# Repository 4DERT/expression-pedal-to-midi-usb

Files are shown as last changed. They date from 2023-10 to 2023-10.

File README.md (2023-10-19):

# Expression pedal to MIDI USB

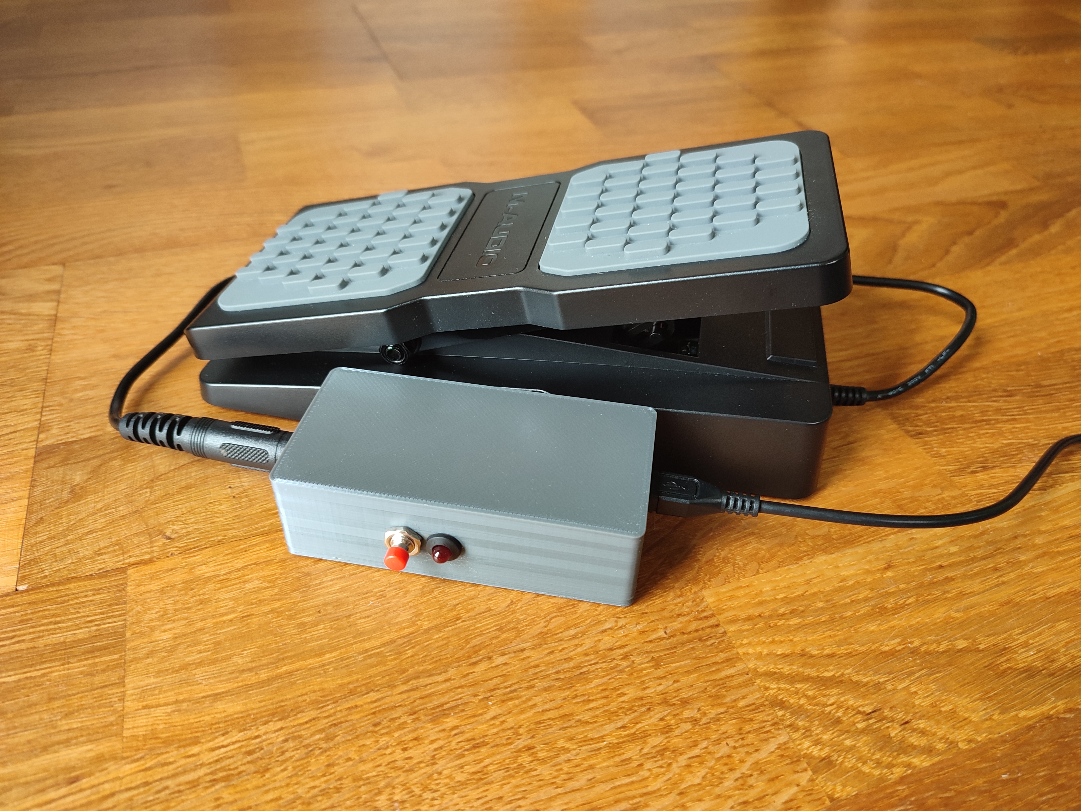
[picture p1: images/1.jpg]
<br>
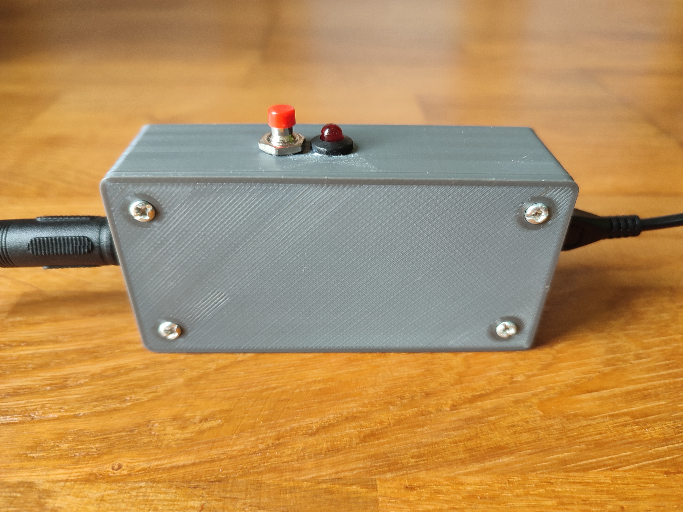
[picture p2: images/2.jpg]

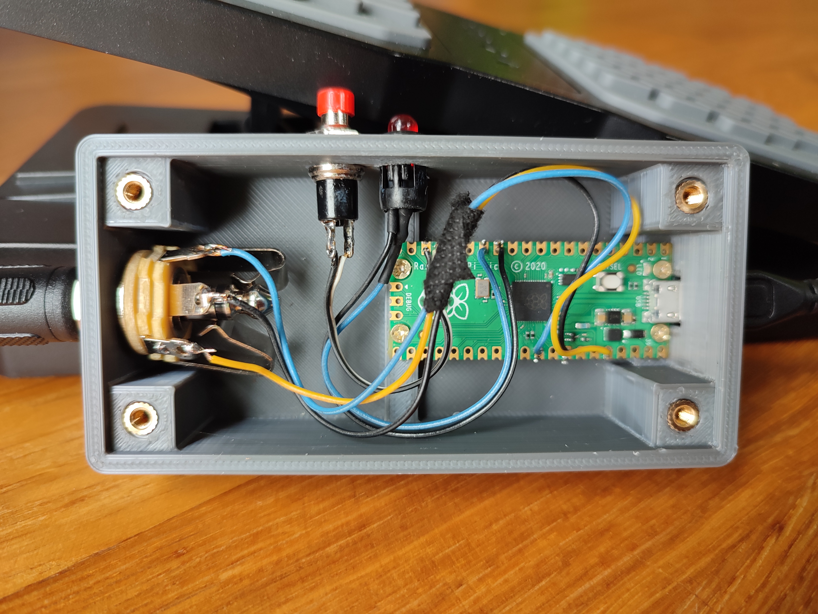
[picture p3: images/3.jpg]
<br>

A Raspberry Pi Pico-based device that takes an expression pedal output via a TRS 1/4" jack and converts it to a USB output.

## Instalation
Put your Raspberry Pi Pico into Bootsel mode by pressing the Bootsel button and then plug it into your computer. When the device appears as a mass storage device, simply drag and drop the UF2 file.

## Usage 
1. Connect the MIDI expression pedal to the 1/4" TRS stereo jack socket on the device.
2. Connect the device to your computer using a USB cable.
3. [Calibrate your device](#calibration)
4. Open your MIDI software on your computer (e.g., DAW) and configure it to receive data from the device.
5. Begin using the MIDI expression pedal, and the device will transmit the data to your computer.

## Calibration
1. Hold the button on the side of the device until the LED light starts flashing slowly.
2. Next, move your pedal from the minimum to the maximum position and set it approximately in the middle position.
3. Once you've completed step 2, press the button again. The LED will start flashing rapidly, indicating that the device is learning electrical noise values to prevent unintentional data transmission to the computer when you're not moving the pedal.
4. To finish the calibration process, press the button once more. The settings will be saved in the flash memory and will load automatically during the next device startup.

## Parts List:
- Raspberry Pi Pico
- 1/4" TRS stereo jack socket
- 5mm LED 
- [5mm LED Holder](https://www.amazon.com/50Pcs-Holder-Socket-Light-emitting-Plastic/dp/B07NRX2YNL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)
- 330 Ohm resistor
- [7mm Momentary Push button Switch](https://www.aliexpress.com/item/32790920961.html)
- Some cables
- 4x M2 6mm screws
- 4x M3 Thread Knurled Brass Threaded Heat Set
- 4x M3 Head Bolt

You can print the case on a 3D printer, the files are in the folder 'stl'

## Schematic
<br>

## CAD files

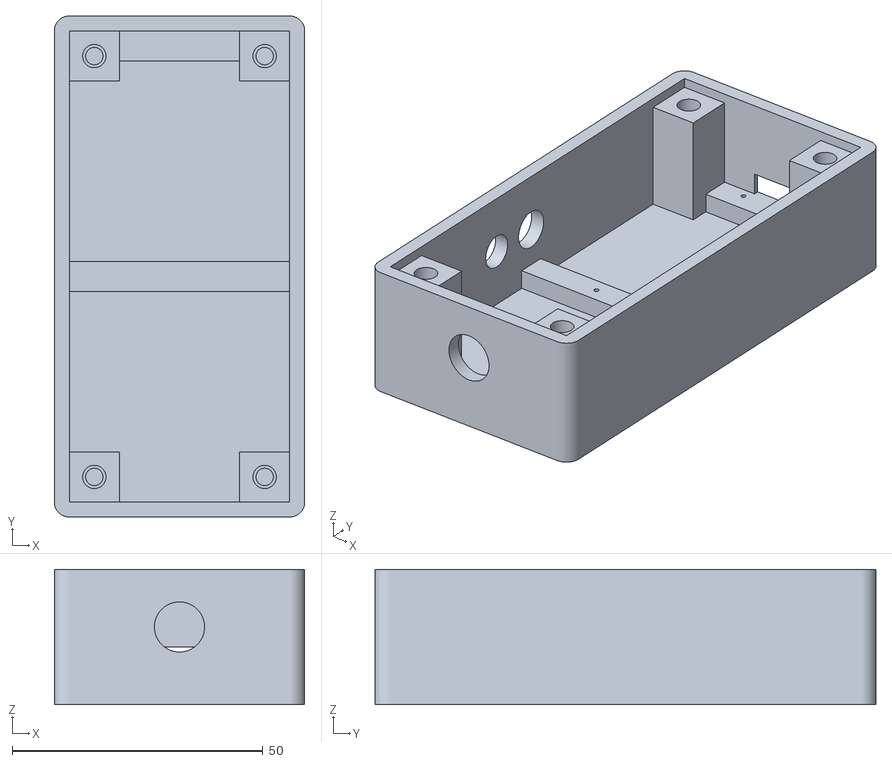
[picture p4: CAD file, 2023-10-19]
stl/midi_usb_main.stl
50.0 x 100.0 x 27.0

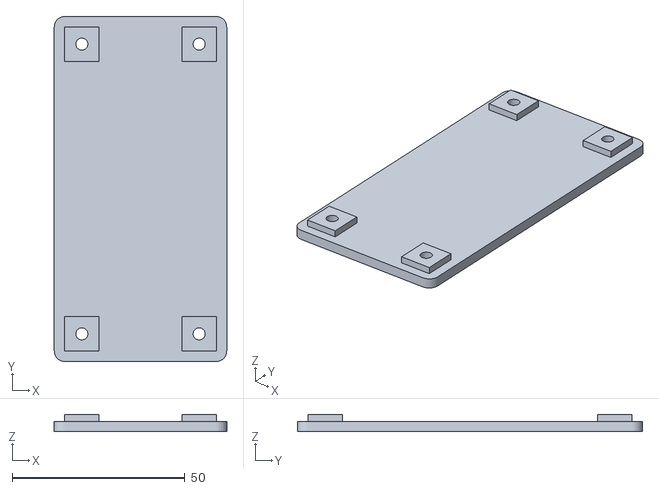
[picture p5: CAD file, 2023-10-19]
stl/midi_usb_top.stl
50.0 x 100.0 x 5.00

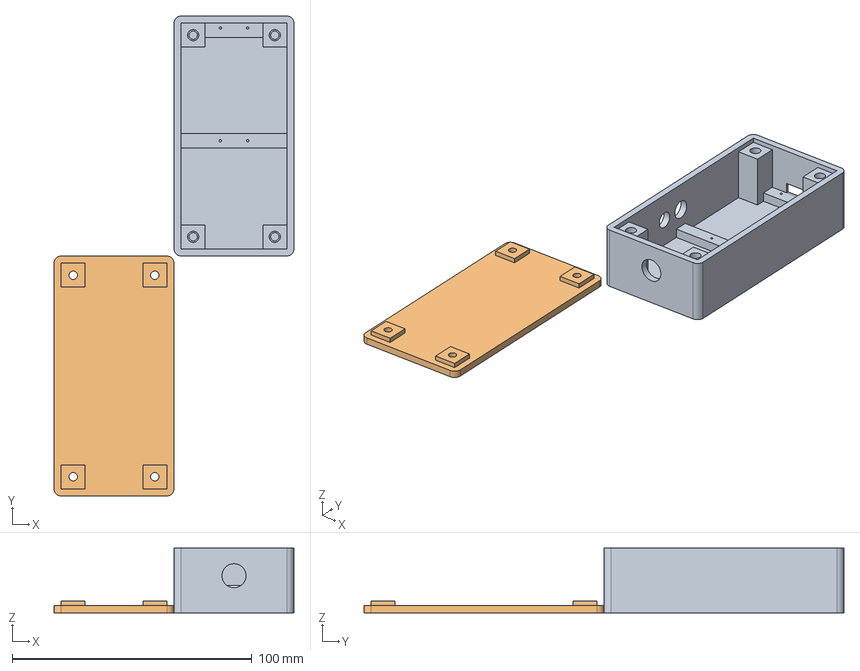
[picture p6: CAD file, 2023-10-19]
stl/midi_usb.FCStd
100.0 x 200.0 x 27.0 mm
base
top

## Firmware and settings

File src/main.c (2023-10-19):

#include <hardware/flash.h>
#include <hardware/gpio.h>
#include <pico/bootrom.h>
#include <stdint.h>
#include <stdio.h>
#include <stdlib.h>
#include <string.h>

#include "button.h"
#include "exp_pedal.h"
#include "flash.hpp"
#include "led.h"
#include "midi.h"
#include "pwm_modulation.h"
#include "tusb.h"

#define LED_GPIO 10
#define BUTTON_GPIO 13
#define PEDAL_GPIO 26
#define PEDAL_ADC_INPUT 0

#define BLINK_TIME_MS_CALIBRATION_1 500
#define BLINK_TIME_MS_CALIBRATION_2 100
#define BLINK_TIME_MS_USB_NOT_CONNECTED 2000

button_t button;
led_t led;

void read_midi_task(void);
void on_button_action(button_interaction_type interaction);

/*------------- MAIN -------------*/
int main(void) {
  // rescue option to enter bootsel
  const uint32_t btn = BUTTON_GPIO;
  gpio_init(btn);
  gpio_set_dir(btn, GPIO_IN);
  gpio_pull_up(btn);
  sleep_ms(250);
  if (!gpio_get(btn))
    reset_usb_boot(0, 0);

  // led init
  led.gpio = LED_GPIO;
  led_init(&led);
  led_blink(&led, BLINK_TIME_MS_USB_NOT_CONNECTED);
  led_pwm_pedal_modulation_init(&led);

  // button init
  button.gpio = BUTTON_GPIO;
  button_init(&button, on_button_action);

  // adc pedal init
  setup_exp_pedal(PEDAL_GPIO, PEDAL_ADC_INPUT);

  // read pedal calibration from flash
  flash_read(&expression_pedal_calibration, sizeof(expression_pedal_calibration));

  // init device stack on configured roothub port
  tud_init(BOARD_TUD_RHPORT);

  turn_on_pedal();

  while (1) {
    tud_task();
    read_midi_task();
    expression_pedal_task();
    button_task(&button);
    led_task(&led);
    led_pwm_pedal_modulation_task(get_current_pos_midi());
  }

  return 0;
}

//--------------------------------------------------------------------+
// Device callbacks
//--------------------------------------------------------------------+

// // Invoked when device is mounted
void tud_mount_cb(void) {
  led_off(&led);
  led_pwm_pedal_modulation_enable(&led);
}

// // Invoked when device is unmounted
void tud_umount_cb(void) { led_blink(&led, BLINK_TIME_MS_USB_NOT_CONNECTED); }

// // Invoked when usb bus is suspended
// // remote_wakeup_en : if host allow us  to perform remote wakeup
// // Within 7ms, device must draw an average of current less than 2.5 mA from bus
void tud_suspend_cb(bool remote_wakeup_en) {
  (void)remote_wakeup_en;
  led_off(&led);
  led_pwm_pedal_modulation_disable(&led);
}

// // Invoked when usb bus is resumed
void tud_resume_cb(void) {
  led_off(&led);
  led_pwm_pedal_modulation_enable(&led);
}

//--------------------------------------------------------------------+
// MIDI Task
//--------------------------------------------------------------------+

void read_midi_task(void) {
  // The MIDI interface always creates input and output port/jack descriptors
  // regardless of these being used or not. Therefore incoming traffic should be
  // read (possibly just discarded) to avoid the sender blocking in IO
  uint8_t packet[4];
  while (tud_midi_available())
    tud_midi_packet_read(packet);
}

void on_button_action(button_interaction_type interaction) {
  switch (interaction) {
    case PRESS:
      if (expression_pedal_get_mode() == CALIBRATION_RANGE) {
        expression_pedal_set_mode(CALIBRATION_NOISE);
        led_blink(&led, BLINK_TIME_MS_CALIBRATION_2);

      } else if (expression_pedal_get_mode() == CALIBRATION_NOISE) {
        expression_pedal_set_mode(NORMAL);
        led_off(&led);

        // save calibration into flash
        flash_write(&expression_pedal_calibration, sizeof(expression_pedal_calibration));

        led_pwm_pedal_modulation_enable(&led);
      }

      break;

    case RELEASE:

      break;

    case LONG_PRESS:
      led_pwm_pedal_modulation_disable(&led);
      led_blink(&led, BLINK_TIME_MS_CALIBRATION_1);
      expression_pedal_set_mode(CALIBRATION_RANGE);

      break;

    default:
      break;
  }
}

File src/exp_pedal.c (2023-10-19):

#include "exp_pedal.h"

#include <hardware/adc.h>
#include <tusb.h>

static uint8_t midi_channel = 0;
static const uint8_t midi_cable_num = 0;

static bool is_on = true;
exp_pedal_mode_t mode = NORMAL;

expression_pedal_calibration_t expression_pedal_calibration;

// variables nedded in calibration procedure
static uint16_t range_adc_min = UINT16_MAX;
static uint16_t range_adc_max = 0;
static uint16_t noise_adc_min = UINT16_MAX;
static uint16_t noise_adc_max = 0;

static uint8_t current_pos_midi;

uint8_t get_current_pos_midi() {
  return current_pos_midi;
}

void turn_off_pedal() {
  is_on = false;
}

void turn_on_pedal() {
  is_on = true;
}

bool is_pedal_on() {
  return is_on;
}

void setup_exp_pedal(uint8_t gpio_pin, uint8_t adc_input) {
  adc_init();
  adc_gpio_init(gpio_pin);
  adc_select_input(adc_input);
}

static uint16_t map(uint16_t x, uint16_t in_min, uint16_t in_max, uint16_t out_min,
                    uint16_t out_max) {
  return (x - in_min) * (out_max - out_min) / (in_max - in_min) + out_min;
}

bool read_pedal_value(uint8_t *midi_value_ptr) {
  static uint16_t vadc = 0;
  static int16_t prev_midi_value = 0;

  uint16_t adc = adc_read();

  if (vadc < adc - expression_pedal_calibration.adc_window)
    vadc += 1;
  else if (vadc > adc + expression_pedal_calibration.adc_window)
    vadc -= 1;

  if (vadc < adc - expression_pedal_calibration.adc_speed || vadc > adc + expression_pedal_calibration.adc_speed) {
    if (vadc < adc - expression_pedal_calibration.adc_speed)
      vadc += expression_pedal_calibration.adc_speed - 1;
    else if (vadc > adc + expression_pedal_calibration.adc_speed)
      vadc -= expression_pedal_calibration.adc_speed - 1;
  }

  if (adc <= expression_pedal_calibration.adc_window)
    vadc = 0;
  if (adc == 4096)
    vadc = 4096;

  int16_t midi_value = map(vadc, expression_pedal_calibration.adc_lowest_value, expression_pedal_calibration.adc_highest_value, 0, 127);

  if (midi_value > 127)
    midi_value = 127;

  if (midi_value < 0)
    midi_value = 0;

  if (midi_value != prev_midi_value) {
    prev_midi_value = midi_value;

    *midi_value_ptr = (uint8_t)midi_value;

    return true;
  }

  return false;
}

void expression_pedal_normal_task() {
  // static uint8_t pedal_pos = 0;

  if (read_pedal_value(&current_pos_midi)) {
    uint8_t cc[3] = {0xB9 | midi_channel, 11, current_pos_midi};
    tud_midi_stream_write(midi_cable_num, cc, 3);
  }
}

void expression_pedal_calibration_range_task() {
  if (!is_on)
    return;

  uint16_t pedal_pos = adc_read();

  if (pedal_pos < range_adc_min) {
    range_adc_min = pedal_pos;
  }

  if (pedal_pos > range_adc_max) {
    range_adc_max = pedal_pos;
  }
}

void expression_pedal_calibration_noise_task() {
  if (!is_on)
    return;

  uint16_t pedal_pos = adc_read();

  if (pedal_pos < noise_adc_min) {
    noise_adc_min = pedal_pos;
  }

  if (pedal_pos > noise_adc_max) {
    noise_adc_max = pedal_pos;
  }
}

void expresson_pedal_on_calibration_end() {
  uint16_t noise_value = noise_adc_max - noise_adc_min;

  // save calibration
  expression_pedal_calibration.adc_lowest_value = range_adc_min + noise_value;
  expression_pedal_calibration.adc_highest_value = range_adc_max - noise_value;
  expression_pedal_calibration.adc_window = noise_value;
  expression_pedal_calibration.adc_speed = noise_value;
}

void expression_pedal_on_calibration_start() {
  range_adc_min = UINT16_MAX;
  range_adc_max = 0;
  noise_adc_min = UINT16_MAX;
  noise_adc_max = 0;
}

void expression_pedal_task() {
  if (!is_on)
    return;

  switch (mode) {
    case NORMAL:
      expression_pedal_normal_task();
      break;

    case CALIBRATION_RANGE:
      expression_pedal_calibration_range_task();
      break;

    case CALIBRATION_NOISE:
      expression_pedal_calibration_noise_task();
      break;

    default:
      break;
  }
}

void expression_pedal_set_mode(exp_pedal_mode_t m) {
  if (mode == NORMAL && (m == CALIBRATION_NOISE || m == CALIBRATION_RANGE)) {
    expression_pedal_on_calibration_start();
  }

  if ((mode == CALIBRATION_NOISE || mode == CALIBRATION_RANGE) && m == NORMAL) {
    expresson_pedal_on_calibration_end();
  }

  mode = m;
}

extern exp_pedal_mode_t expression_pedal_get_mode() {
  return mode;
}
